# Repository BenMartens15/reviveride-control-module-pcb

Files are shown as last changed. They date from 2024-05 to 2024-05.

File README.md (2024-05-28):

# ReviveRide: Modernizing Vintage Autos
### Project Overview
ReviveRide was developed as a capstone project for the Computer Engineering Technology program at Conestoga College. The goal of ReviveRide is to bring features found on modern vehicles to older vehicles. The project provides a dash camera, backup camera, head unit touchscreen with Android Auto, blind spot object detection, and remote start in an all-in-one, easy to install kit.

### Control Module
The control module is responsible for providing power to every component in the system when the car is turned on. It is also responsible for receiving the remote start signal from the key fob and switching voltages to the ignition system to start the car.

This repo contains the schematic and PCB for the control module. The firmware for the control module can be found here: https://github.com/BenMartens15/reviveride-control-module-firmware

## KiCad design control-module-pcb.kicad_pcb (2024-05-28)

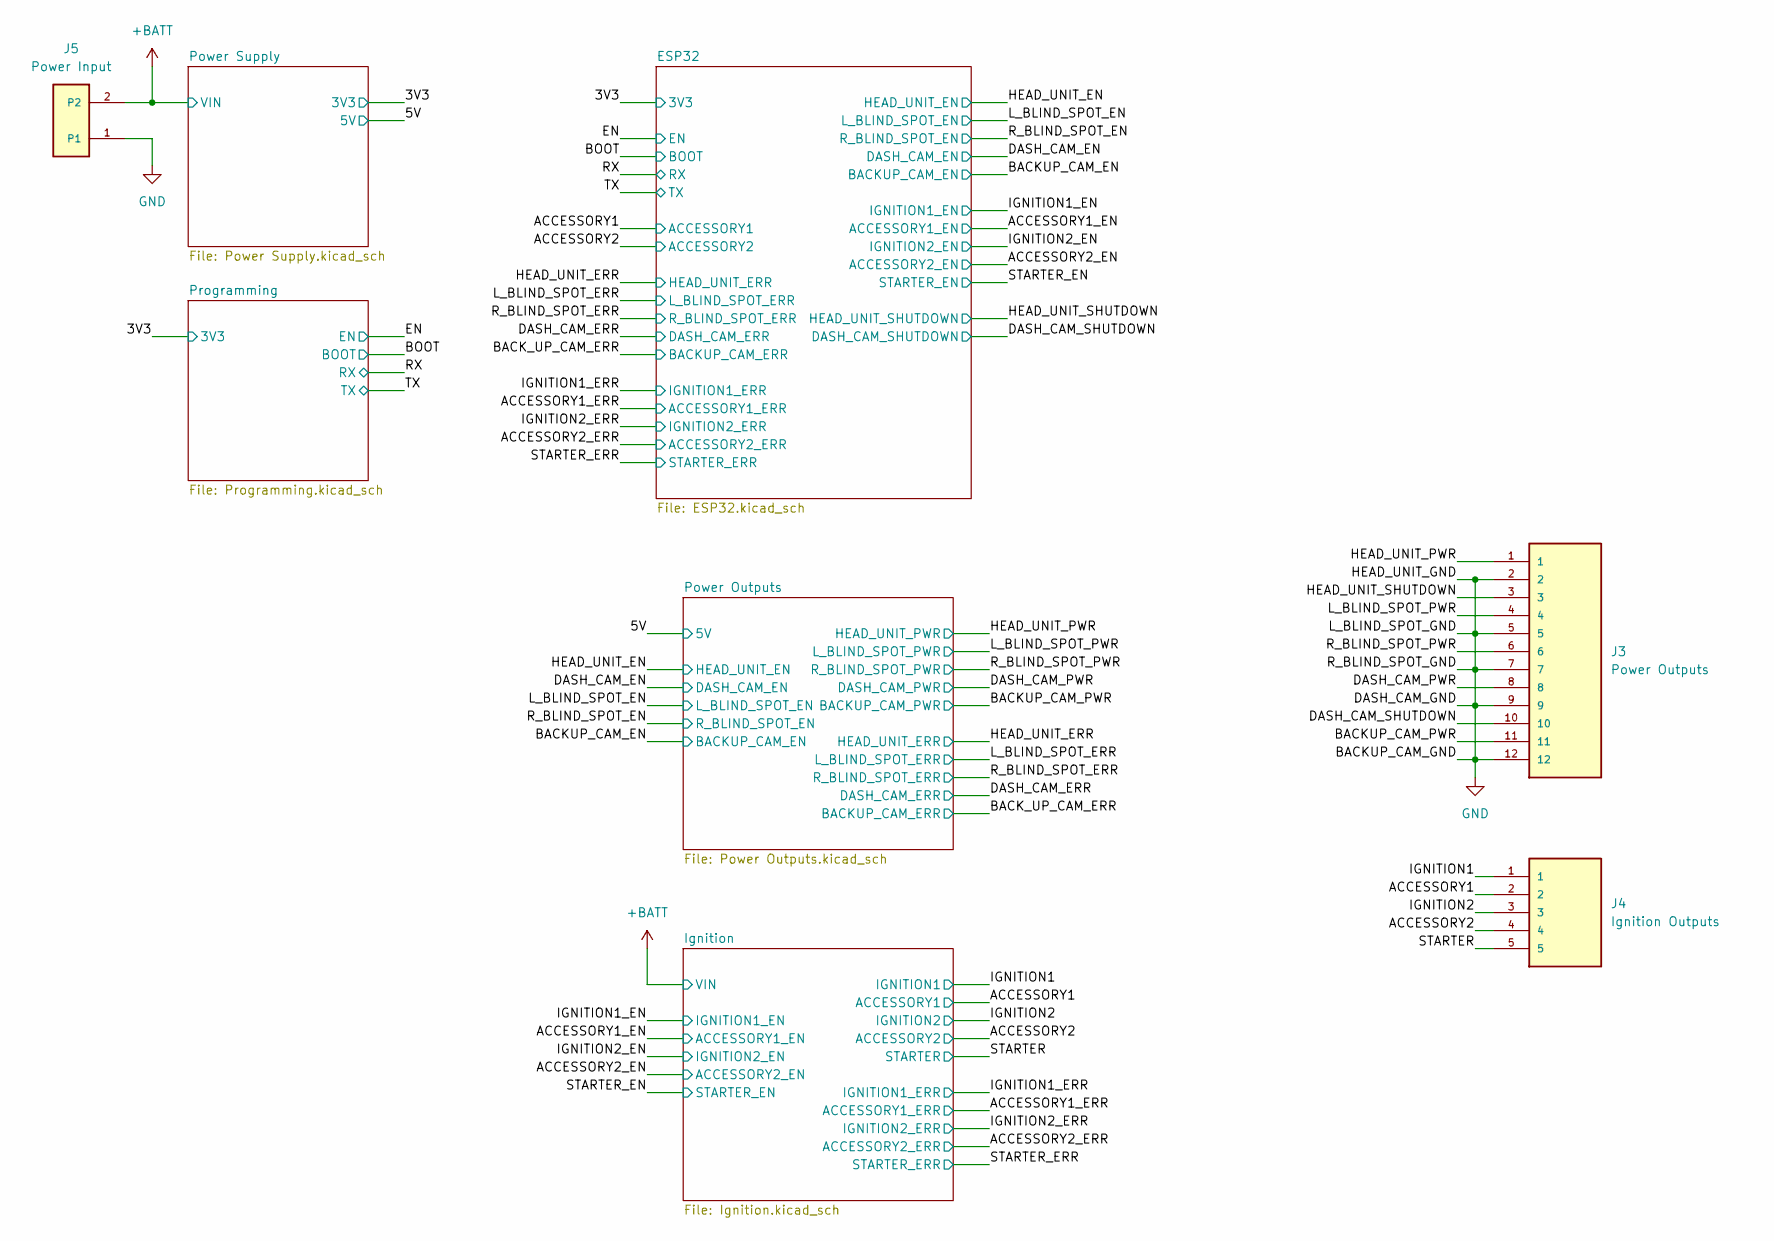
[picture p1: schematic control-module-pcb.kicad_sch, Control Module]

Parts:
J3: Power Outputs; TE_1-1776275-2; PARTREV R
J4: Ignition Outputs; TE_1776275-5; PARTREV R
J5: Power Input; TE_1776275-2; VOLTAGE_RATING_AC 250V; PART_DESCRIPTION TERM BLOCK 2POS SIDE ENT 3.5MM

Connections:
+BATT: J5.2; also elsewhere on the board
/ACCESSORY1: J4.2; also elsewhere on the board
/ACCESSORY2: J4.4; also elsewhere on the board
/BACKUP_CAM_PWR: J3.11; also elsewhere on the board
/DASH_CAM_PWR: J3.8; also elsewhere on the board
/DASH_CAM_SHUTDOWN: J3.10; also elsewhere on the board
/HEAD_UNIT_PWR: J3.1; also elsewhere on the board
/HEAD_UNIT_SHUTDOWN: J3.3; also elsewhere on the board
/IGNITION1: J4.1; also elsewhere on the board
/IGNITION2: J4.3; also elsewhere on the board
/L_BLIND_SPOT_PWR: J3.4; also elsewhere on the board
/R_BLIND_SPOT_PWR: J3.6; also elsewhere on the board
/STARTER: J4.5; also elsewhere on the board
GND: J3.2, J3.5, J3.7, J3.9, J3.12, J5.1; also elsewhere on the board

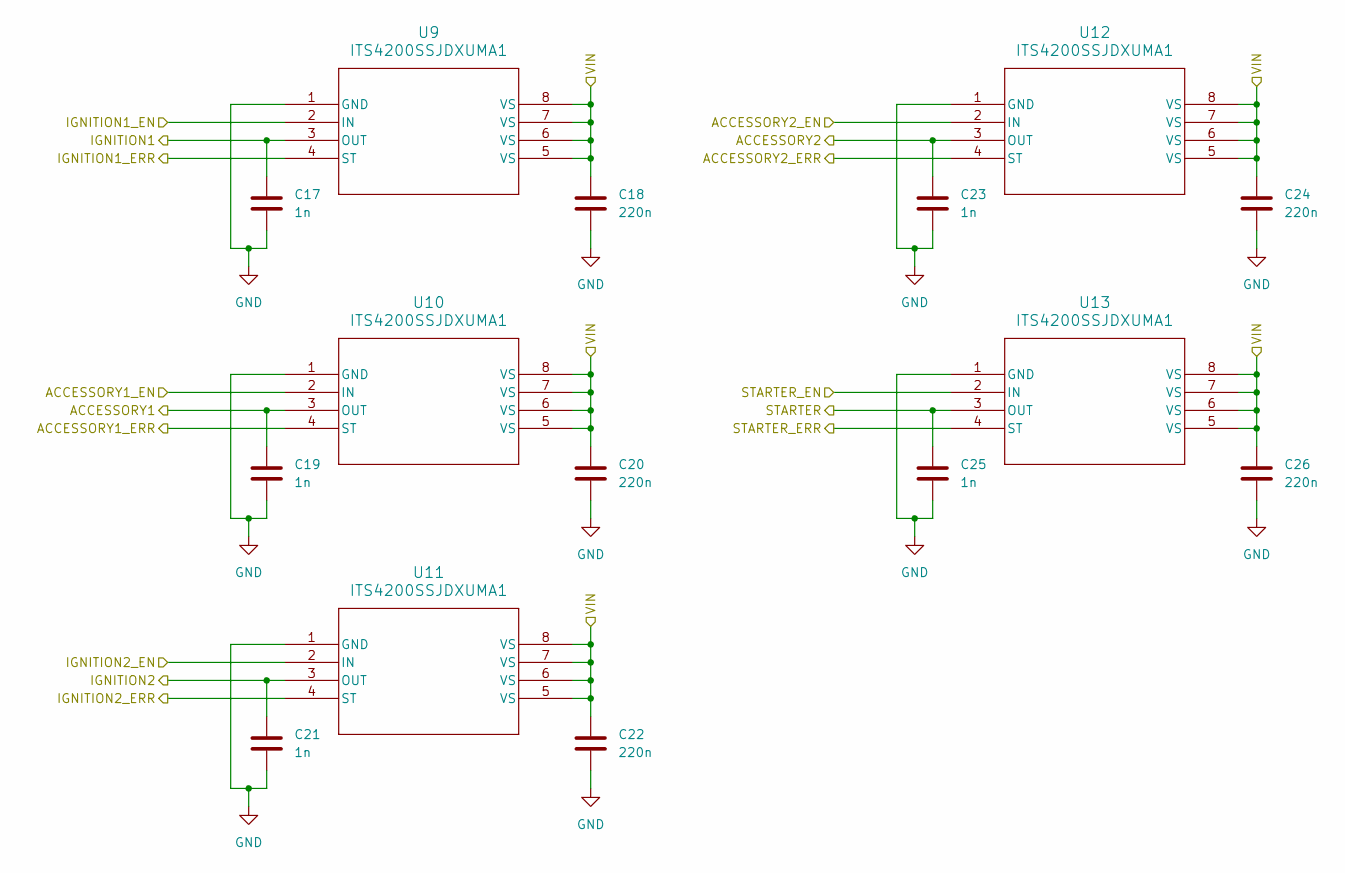
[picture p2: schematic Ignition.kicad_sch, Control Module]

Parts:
C17, C19, C21, C23, C25: 1n; C_0603_1608Metric
C18, C20, C22, C24, C26: 220n; C_0603_1608Metric
U9, U10, U11, U12, U13: ITS4200SSJDXUMA1; PG-DSO-8-24_INF

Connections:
+BATT: C18.2, C20.2, C22.2, C24.2, C26.2, U9.5 (VS), U9.6 (VS), U9.7 (VS), U9.8 (VS), U10.5 (VS), U10.6 (VS), U10.7 (VS), U10.8 (VS), U11.5 (VS), U11.6 (VS), U11.7 (VS), U11.8 (VS), U12.5 (VS), U12.6 (VS), U12.7 (VS), U12.8 (VS), U13.5 (VS), U13.6 (VS), U13.7 (VS), U13.8 (VS); also elsewhere on the board
/ACCESSORY1: C19.2, U10.3 (OUT); also elsewhere on the board
/ACCESSORY1_EN: U10.2 (IN); also elsewhere on the board
/ACCESSORY1_ERR: U10.4 (ST); also elsewhere on the board
/ACCESSORY2: C23.2, U12.3 (OUT); also elsewhere on the board
/ACCESSORY2_EN: U12.2 (IN); also elsewhere on the board
/ACCESSORY2_ERR: U12.4 (ST); also elsewhere on the board
/IGNITION1: C17.2, U9.3 (OUT); also elsewhere on the board
/IGNITION1_EN: U9.2 (IN); also elsewhere on the board
/IGNITION1_ERR: U9.4 (ST); also elsewhere on the board
/IGNITION2: C21.2, U11.3 (OUT); also elsewhere on the board
/IGNITION2_EN: U11.2 (IN); also elsewhere on the board
/IGNITION2_ERR: U11.4 (ST); also elsewhere on the board
/STARTER: C25.2, U13.3 (OUT); also elsewhere on the board
/STARTER_EN: U13.2 (IN); also elsewhere on the board
/STARTER_ERR: U13.4 (ST); also elsewhere on the board
GND: C17.1, C18.1, C19.1, C20.1, C21.1, C22.1, C23.1, C24.1, C25.1, C26.1, U9.1 (GND), U10.1 (GND), U11.1 (GND), U12.1 (GND), U13.1 (GND); also elsewhere on the board

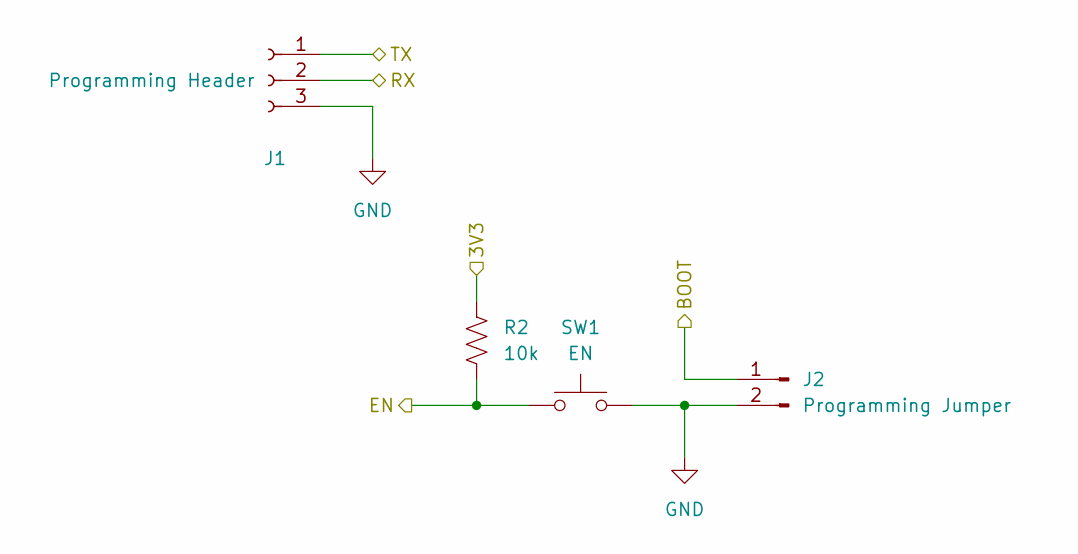
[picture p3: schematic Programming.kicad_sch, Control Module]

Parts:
J1: Programming Header; PinHeader_1x03_P2.54mm_Horizontal
J2: Programming Jumper; PinHeader_1x02_P2.54mm_Horizontal
R2: 10k; R_0603_1608Metric
SW1: EN; SW_SPST_TL3305B

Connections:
/3V3: R2.1; also elsewhere on the board
/BOOT: J2.1; also elsewhere on the board
/EN: R2.2, SW1.2; also elsewhere on the board
/RX: J1.2; also elsewhere on the board
/TX: J1.1; also elsewhere on the board
GND: J1.3, J2.2, SW1.1; also elsewhere on the board

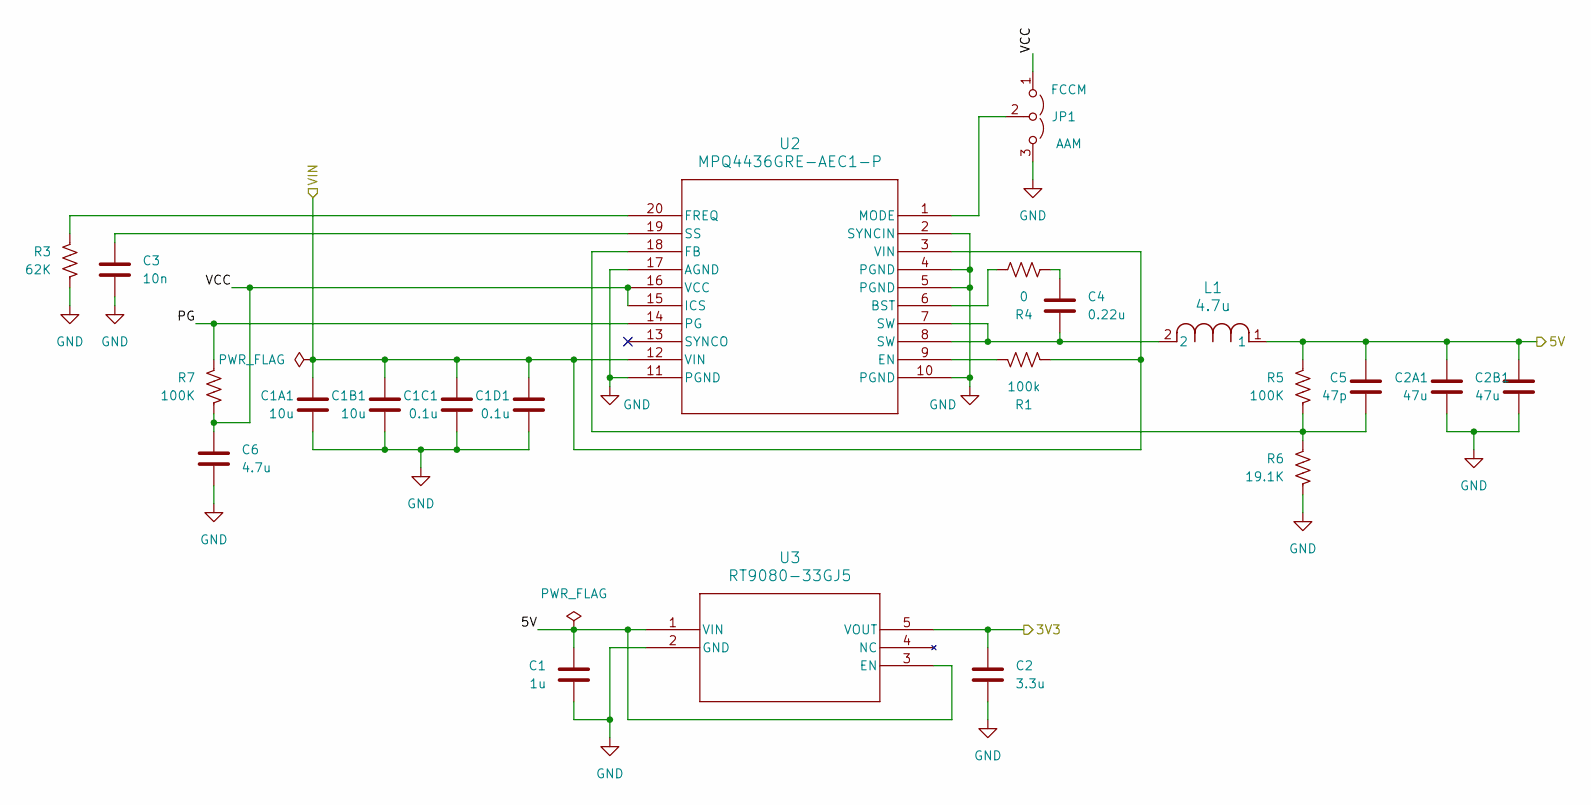
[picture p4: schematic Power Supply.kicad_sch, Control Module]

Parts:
C1: 1u; C_0603_1608Metric
C1A1, C1B1: 10u; C_1206_3216Metric
C1C1, C1D1: 0.1u; C_0603_1608Metric
C2: 3.3u; C_0603_1608Metric
C2A1, C2B1: 47u; C_1206_3216Metric
C3: 10n; C_0603_1608Metric
C4: 0.22u; C_0603_1608Metric
C5: 47p; C_0603_1608Metric
C6: 4.7u; C_0603_1608Metric
JP1: PinHeader_1x03_P2.54mm_Vertical
L1: 4.7u; IND_PA4342_PUL
R1: 100k; R_0603_1608Metric
R3: 62K; R_0603_1608Metric
R4: 0; R_0603_1608Metric
R5, R7: 100K; R_0603_1608Metric
R6: 19.1K; R_0603_1608Metric
U2: MPQ4436GRE-AEC1-P; QFN-4x4_MPQ4436-AEC1_MNP
U3: RT9080-33GJ5; TSOT-23-5_RIT

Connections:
+BATT: C1A1.1, C1B1.1, C1C1.1, C1D1.1, R1.2, U2.3 (VIN), U2.12 (VIN); also elsewhere on the board
/3V3: C2.1, U3.5 (VOUT); also elsewhere on the board
/5V: C1.1, C2A1.1, C2B1.1, C5.1, L1.1, R5.1, U3.1 (VIN), U3.3 (EN); also elsewhere on the board
/Power Supply/PG: R7.1, U2.14 (PG)
/Power Supply/VCC: C6.1, JP1.1 (A), R7.2, U2.15 (ICS), U2.16 (VCC)
GND: C1.2, C1A1.2, C1B1.2, C1C1.2, C1D1.2, C2.2, C2A1.2, C2B1.2, C3.2, C6.2, JP1.3 (B), R3.2, R6.2, U2.2 (SYNCIN), U2.4 (PGND), U2.5 (PGND), U2.10 (PGND), U2.11 (PGND), U2.17 (AGND), U3.2 (GND); also elsewhere on the board
unnamed: C4.1, L1.2, U2.7 (SW), U2.8 (SW)
unnamed: C4.2, R4.1
unnamed: JP1.2 (C), U2.1 (MODE)
unnamed: R4.2, U2.6 (BST)
unnamed: R1.1, U2.9 (EN)
unnamed: C5.2, R5.2, R6.1, U2.18 (FB)
unnamed: R3.1, U2.20 (FREQ)
unnamed: C3.1, U2.19 (SS)

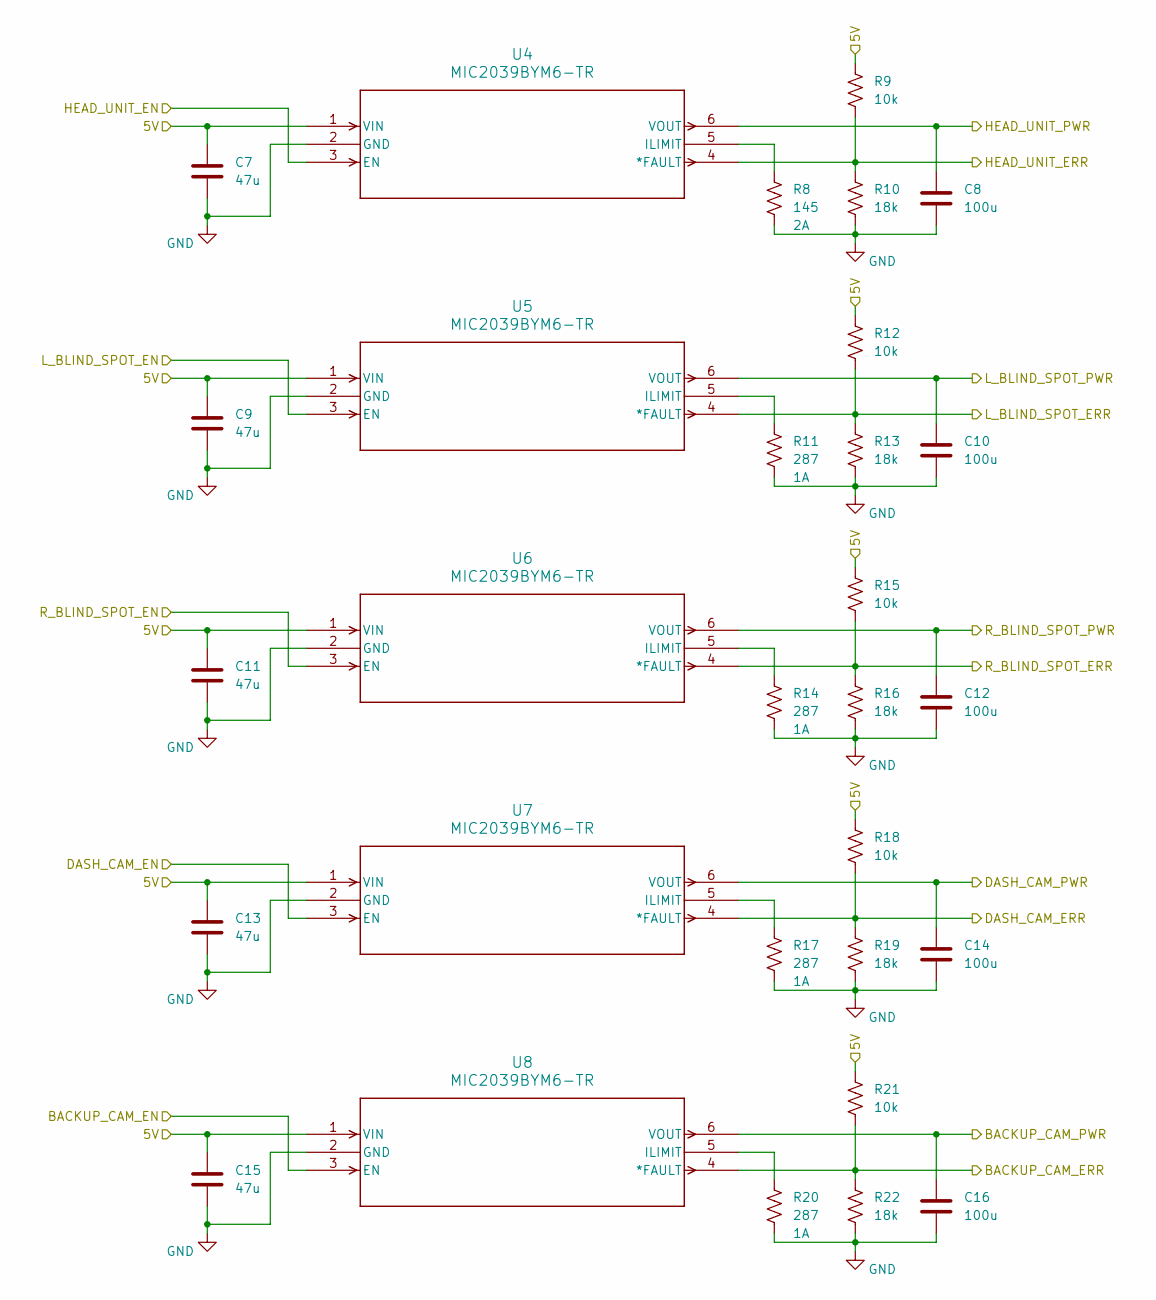
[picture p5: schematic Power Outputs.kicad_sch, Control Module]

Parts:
C7, C9, C11, C13, C15: 47u; C_1206_3216Metric
C8, C10, C12, C14, C16: 100u; C_1206_3216Metric
R8: 145; R_0603_1608Metric
R9, R12, R15, R18, R21: 10k; R_0603_1608Metric
R10, R13, R16, R19, R22: 18k; R_0603_1608Metric
R11, R14, R17, R20: 287; R_0603_1608Metric
U4, U5, U6, U7, U8: MIC2039BYM6-TR; SOT-23-6_M6_MCH

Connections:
/5V: C7.1, C9.1, C11.1, C13.1, C15.1, R9.1, R12.1, R15.1, R18.1, R21.1, U4.1 (VIN), U5.1 (VIN), U6.1 (VIN), U7.1 (VIN), U8.1 (VIN); also elsewhere on the board
/BACKUP_CAM_EN: U8.3 (EN); also elsewhere on the board
/BACKUP_CAM_PWR: C16.1, U8.6 (VOUT); also elsewhere on the board
/BACK_UP_CAM_ERR: R21.2, R22.1, U8.4 (*FAULT); also elsewhere on the board
/DASH_CAM_EN: U7.3 (EN); also elsewhere on the board
/DASH_CAM_ERR: R18.2, R19.1, U7.4 (*FAULT); also elsewhere on the board
/DASH_CAM_PWR: C14.1, U7.6 (VOUT); also elsewhere on the board
/HEAD_UNIT_EN: U4.3 (EN); also elsewhere on the board
/HEAD_UNIT_ERR: R9.2, R10.1, U4.4 (*FAULT); also elsewhere on the board
/HEAD_UNIT_PWR: C8.1, U4.6 (VOUT); also elsewhere on the board
/L_BLIND_SPOT_EN: U5.3 (EN); also elsewhere on the board
/L_BLIND_SPOT_ERR: R12.2, R13.1, U5.4 (*FAULT); also elsewhere on the board
/L_BLIND_SPOT_PWR: C10.1, U5.6 (VOUT); also elsewhere on the board
/R_BLIND_SPOT_EN: U6.3 (EN); also elsewhere on the board
/R_BLIND_SPOT_ERR: R15.2, R16.1, U6.4 (*FAULT); also elsewhere on the board
/R_BLIND_SPOT_PWR: C12.1, U6.6 (VOUT); also elsewhere on the board
GND: C7.2, C8.2, C9.2, C10.2, C11.2, C12.2, C13.2, C14.2, C15.2, C16.2, R8.2, R10.2, R11.2, R13.2, R14.2, R16.2, R17.2, R19.2, R20.2, R22.2, U4.2 (GND), U5.2 (GND), U6.2 (GND), U7.2 (GND), U8.2 (GND); also elsewhere on the board
unnamed: R8.1, U4.5 (ILIMIT)
unnamed: R11.1, U5.5 (ILIMIT)
unnamed: R14.1, U6.5 (ILIMIT)
unnamed: R17.1, U7.5 (ILIMIT)
unnamed: R20.1, U8.5 (ILIMIT)

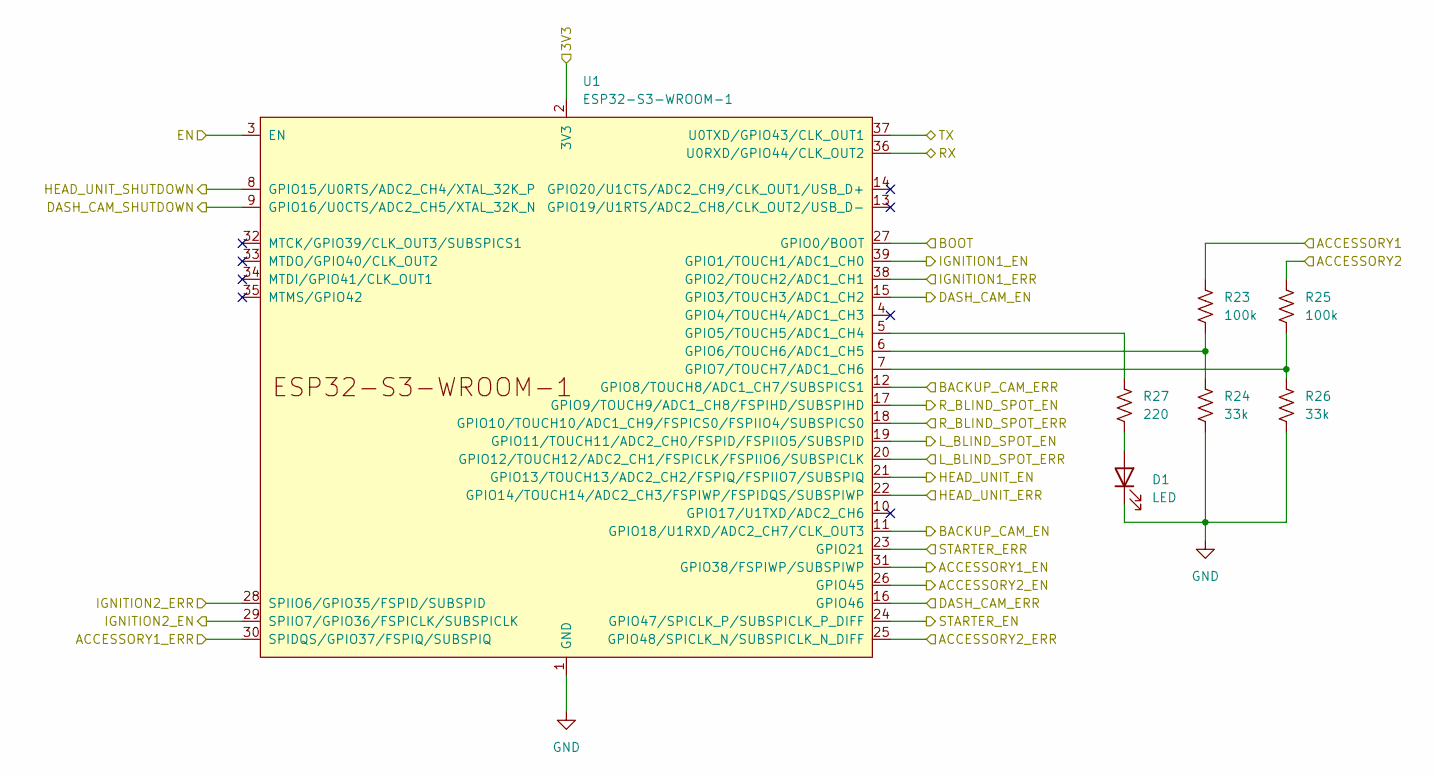
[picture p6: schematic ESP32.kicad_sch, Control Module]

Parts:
D1: LED; LED_0603_1608Metric
R23, R25: 100k; R_0603_1608Metric
R24, R26: 33k; R_0603_1608Metric
R27: 220; R_0603_1608Metric
U1: ESP32-S3-WROOM-1

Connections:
/3V3: U1.2 (3V3); also elsewhere on the board
/ACCESSORY1: R23.1; also elsewhere on the board
/ACCESSORY1_EN: U1.31 (GPIO38/FSPIWP/SUBSPIWP); also elsewhere on the board
/ACCESSORY1_ERR: U1.30 (SPIDQS/GPIO37/FSPIQ/SUBSPIQ); also elsewhere on the board
/ACCESSORY2: R25.1; also elsewhere on the board
/ACCESSORY2_EN: U1.26 (GPIO45); also elsewhere on the board
/ACCESSORY2_ERR: U1.25 (GPIO48/SPICLK_N/SUBSPICLK_N_DIFF); also elsewhere on the board
/BACKUP_CAM_EN: U1.11 (GPIO18/U1RXD/ADC2_CH7/CLK_OUT3); also elsewhere on the board
/BACK_UP_CAM_ERR: U1.12 (GPIO8/TOUCH8/ADC1_CH7/SUBSPICS1); also elsewhere on the board
/BOOT: U1.27 (GPIO0/BOOT); also elsewhere on the board
/DASH_CAM_EN: U1.15 (GPIO3/TOUCH3/ADC1_CH2); also elsewhere on the board
/DASH_CAM_ERR: U1.16 (GPIO46); also elsewhere on the board
/DASH_CAM_SHUTDOWN: U1.9 (GPIO16/U0CTS/ADC2_CH5/XTAL_32K_N); also elsewhere on the board
/EN: U1.3 (EN); also elsewhere on the board
/HEAD_UNIT_EN: U1.21 (GPIO13/TOUCH13/ADC2_CH2/FSPIQ/FSPIIO7/S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); also elsewhere on the board
/HEAD_UNIT_ERR: U1.22 (GPIO14/TOUCH14/ADC2_CH3/FSPIWP/FSPIDQS/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); also elsewhere on the board
/HEAD_UNIT_SHUTDOWN: U1.8 (GPIO15/U0RTS/ADC2_CH4/XTAL_32K_P); also elsewhere on the board
/IGNITION1_EN: U1.39 (GPIO1/TOUCH1/ADC1_CH0); also elsewhere on the board
/IGNITION1_ERR: U1.38 (GPIO2/TOUCH2/ADC1_CH1); also elsewhere on the board
/IGNITION2_EN: U1.29 (SPIIO7/GPIO36/FSPICLK/SUBSPICLK); also elsewhere on the board
/IGNITION2_ERR: U1.28 (SPIIO6/GPIO35/FSPID/SUBSPID); also elsewhere on the board
/L_BLIND_SPOT_EN: U1.19 (GPIO11/TOUCH11/ADC2_CH0/FSPID/FSPIIO5/S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); also elsewhere on the board
/L_BLIND_SPOT_ERR: U1.20 (GPIO12/TOUCH12/ADC2_CH1/FSPICLK/FSPIIO6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); also elsewhere on the board
/RX: U1.36 (U0RXD/GPIO44/CLK_OUT2); also elsewhere on the board
/R_BLIND_SPOT_EN: U1.17 (GPIO9/TOUCH9/ADC1_CH8/FSPIHD/SUBSPIHD); also elsewhere on the board
/R_BLIND_SPOT_ERR: U1.18 (GPIO10/TOUCH10/ADC1_CH9/FSPICS0/FSPIIO4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); also elsewhere on the board
/STARTER_EN: U1.24 (GPIO47/SPICLK_P/SUBSPICLK_P_DIFF); also elsewhere on the board
/STARTER_ERR: U1.23 (GPIO21); also elsewhere on the board
/TX: U1.37 (U0TXD/GPIO43/CLK_OUT1); also elsewhere on the board
GND: D1.1 (K), R24.2, R26.2, U1.1 (GND), U1.40 (GND), U1.41 (GND); also elsewhere on the board
unnamed: D1.2 (A), R27.2
unnamed: R27.1, U1.5 (GPIO5/TOUCH5/ADC1_CH4)
unnamed: R23.2, R24.1, U1.6 (GPIO6/TOUCH6/ADC1_CH5)
unnamed: R25.2, R26.1, U1.7 (GPIO7/TOUCH7/ADC1_CH6)

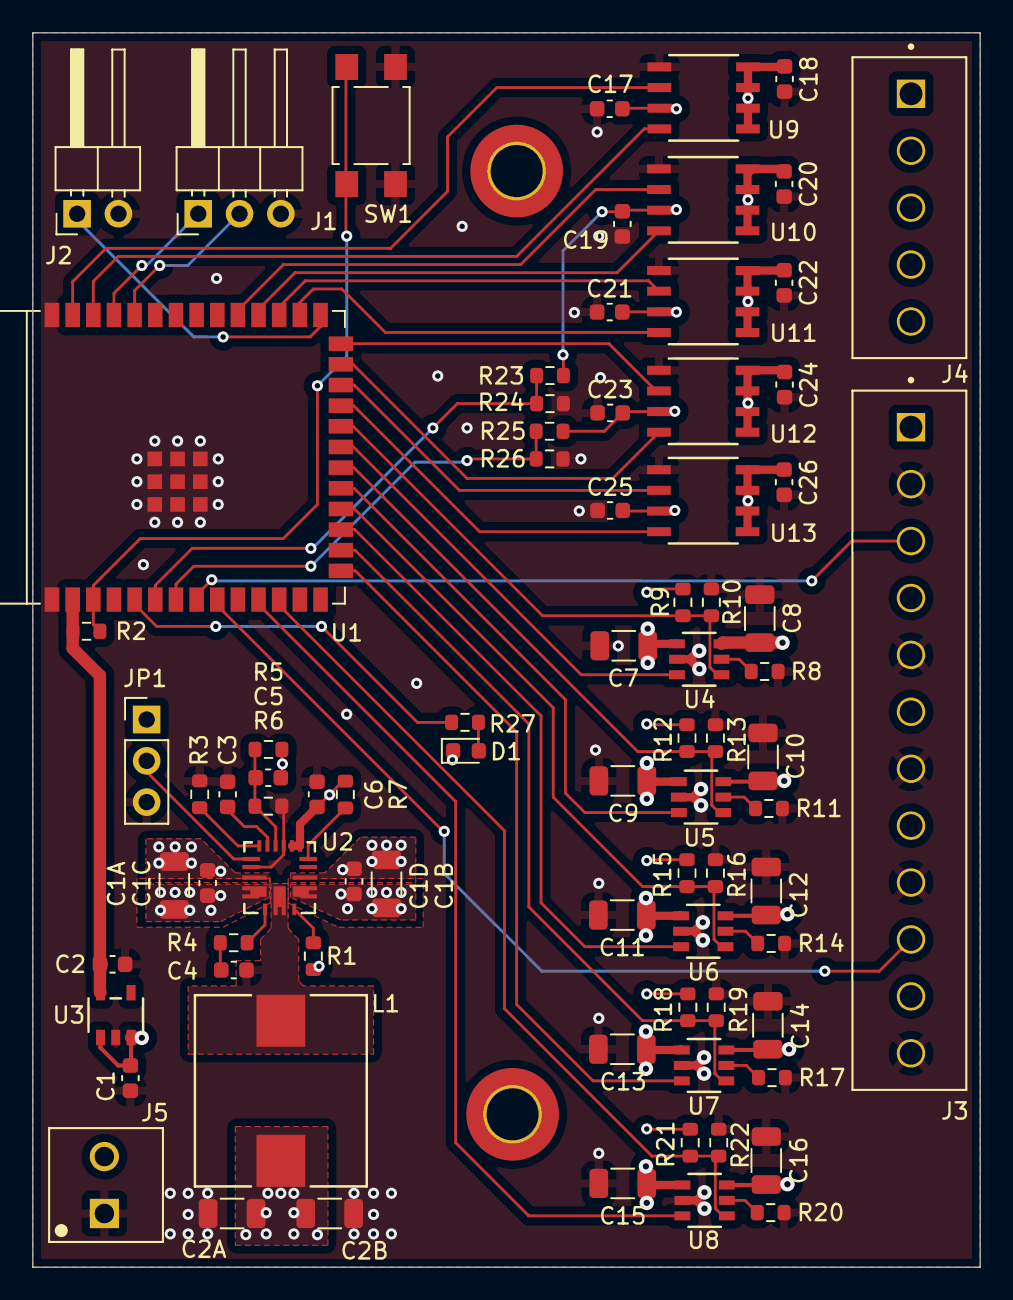
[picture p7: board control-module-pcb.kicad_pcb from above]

Board: 4 copper layers, 58.2 x 75.9 mm, 81 parts (0 on the bottom side), 59 nets.

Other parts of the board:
C1A, C1B: 10u; C_1206_3216Metric
C1C, C1D: 0.1u; C_0603_1608Metric
C2A, C2B: 47u; C_1206_3216Metric

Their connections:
+BATT: C1A.1, C1B.1, C1C.1, C1D.1; also elsewhere on the board
/5V: C2A.1, C2B.1; also elsewhere on the board
GND: C1A.2, C1B.2, C1C.2, C1D.2, C2A.2, C2B.2; also elsewhere on the board

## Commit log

2023-11-09 created KiCAD project and added PMIC chip library
    [control-module-pcb.kicad_pcb, control-module-pcb.kicad_sch]
2023-11-22 hierarchical sheets and connections done
    [ESP32.kicad_sch, Ignition.kicad_sch, Power Outputs.kicad_sch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]
2023-11-22 power supply circuit schematic done
    [ESP32.kicad_sch, Power Outputs.kicad_sch, Power Supply.kicad_sch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]
2023-11-23 working on ignition and power output sheets
    [Ignition.kicad_sch, Power Outputs.kicad_sch, Power Supply.kicad_sch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]
2023-11-23 assign ESP32 pins
    [ESP32.kicad_sch]
2024-01-24 switch Ignition page to use load drivers rather than discrete FETs
    [ESP32.kicad_sch, Ignition.kicad_sch, Power Outputs.kicad_sch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]
2024-02-01 fix ERC errors
    [ESP32.kicad_sch, Ignition.kicad_sch, Power Outputs.kicad_sch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]
2024-02-06 Assigning footprints
    [ESP32.kicad_sch, Ignition.kicad_sch, Power Outputs.kicad_sch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]
2024-02-08 finished assigning footprints and started PCB layout
    [ESP32.kicad_sch, Power Outputs.kicad_sch, Power Supply.kicad_sch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]
2024-02-08 layout mostly complete
    [ESP32.kicad_sch, control-module-pcb.kicad_pcb, control-module-pcb.kicad_sch]
2024-02-09 made a few adjustments and generated gerbers
    [Power Outputs.kicad_sch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]
2024-02-09 add LED for debugging
    [ESP32.kicad_sch, Power Supply.kicad_sch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]
2024-02-09 a few silk screen updates
    [control-module-pcb-B_Mask.gbs, control-module-pcb-B_Paste.gbp, control-module-pcb-B_Silkscreen.gbo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]
2024-02-13 add 3d models and export step
    [control-module-pcb.kicad_pcb]
2024-02-14 removed blind via from PCB
    [Power Supply.kicad_sch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]
